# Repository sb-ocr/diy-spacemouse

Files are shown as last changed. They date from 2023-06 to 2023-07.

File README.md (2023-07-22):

# DIY Spacemouse for Fusion 360

Watch the build video ↓

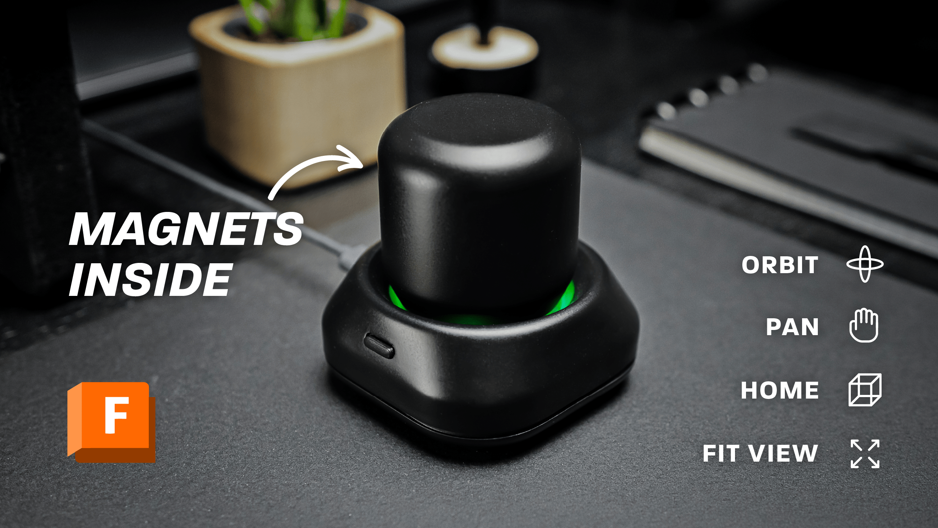
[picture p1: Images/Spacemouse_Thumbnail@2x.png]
[](https://youtu.be/iHBgNGnTiK4)

This device is made for Fusion360 but can be adapted to other CAD applications. Current features: Orbit, Pan, Home view and Fit to view.

Build instructions → [Instructables](https://www.instructables.com/DIY-Space-Mouse-for-Fusion-360-Using-Magnets)

[][cc-by-nc-sa]

[][cc-by-nc-sa]

[cc-by-nc-sa]: http://creativecommons.org/licenses/by-nc-sa/4.0/
[cc-by-nc-sa-image]: https://licensebuttons.net/l/by-nc-sa/4.0/88x31.png
[cc-by-nc-sa-shield]: https://img.shields.io/badge/License-CC%20BY--NC--SA%204.0-lightgrey.svg

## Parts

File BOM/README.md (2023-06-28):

Affiliate links may be included in the BOM. I may receive a small commission at no additional cost to you.

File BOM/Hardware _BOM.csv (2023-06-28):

Qty | Item | Link
6 | Round Magnets (6 × 2mm) | https://geni.us/0oCmMH
3 | Compression Spring 23/64" × 1-3/8" | https://geni.us/mm5tB
3 | Extension Spring 13/64" × 13/16" | https://geni.us/mm5tB
24 | M2.5 × 3.4 mm Heat-Set Inserts | https://geni.us/BMZYH
10 | M2.5 × 3mm Socket Head Screws | https://geni.us/S0KvnqZ
3 | M2.5 × 5mm Socket Head Screws | https://geni.us/S0KvnqZ
7 | M2.5 × 8mm Socket Head Screws | https://geni.us/S0KvnqZ
4 | M2.5 × 12mm Socket Head Screws | https://geni.us/S0KvnqZ

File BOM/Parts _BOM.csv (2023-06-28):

Qty | Item | Link
1 | QT Py RP2040 | https://www.adafruit.com/product/4900
1 | TLV493D Triple-Axis Magnetometer | https://www.adafruit.com/product/4366
1 | STEMMA QT / Qwiic JST SH 4-pin Cable - 100mm Long | https://www.adafruit.com/product/4210
2 | Tactile Button switch (6mm) | https://www.adafruit.com/product/367
3 | Adafruit LED Sequins - Emerald Green (optional) | https://www.adafruit.com/product/1756
4 | Rubber Bumper Feet | https://www.adafruit.com/product/550

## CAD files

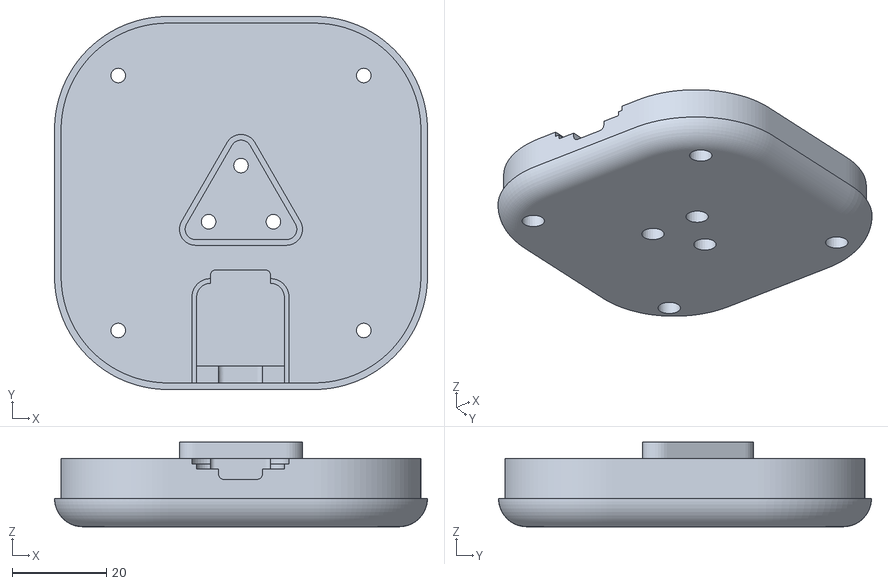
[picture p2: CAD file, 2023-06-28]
CAD/STLs/Base_bottom.stl
79.0 x 79.0 x 17.9

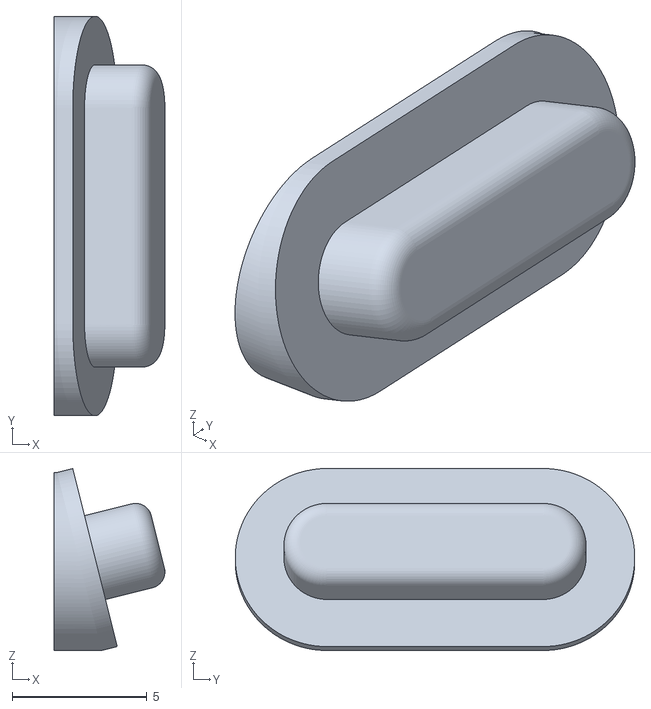
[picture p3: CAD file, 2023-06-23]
CAD/STLs/Buttons.stl
4.10 x 14.8 x 6.74

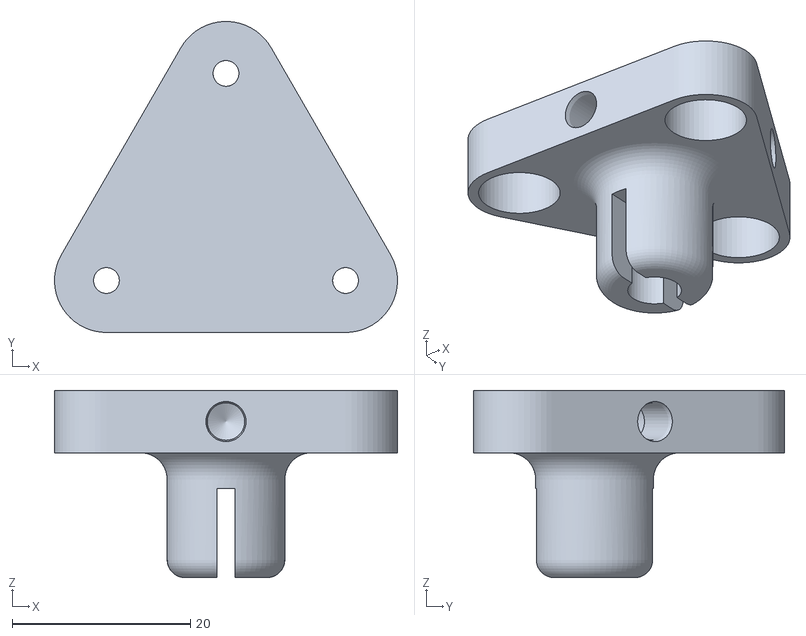
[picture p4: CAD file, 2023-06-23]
CAD/STLs/Stem_top.stl
38.4 x 34.9 x 21.0

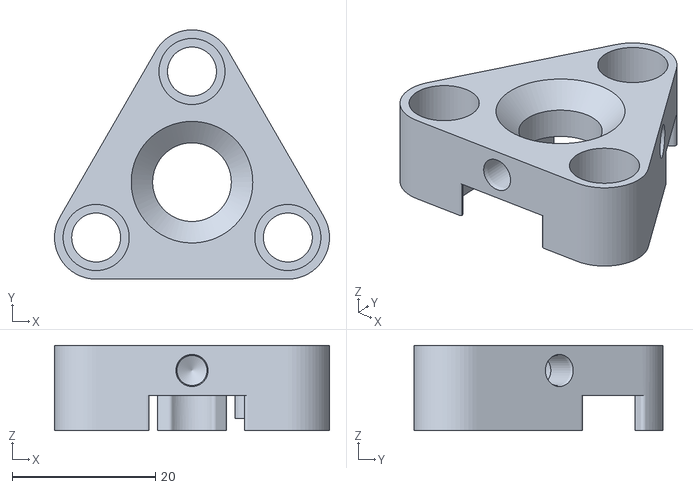
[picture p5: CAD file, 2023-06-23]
CAD/STLs/Stem_middle.stl
38.5 x 34.9 x 11.9

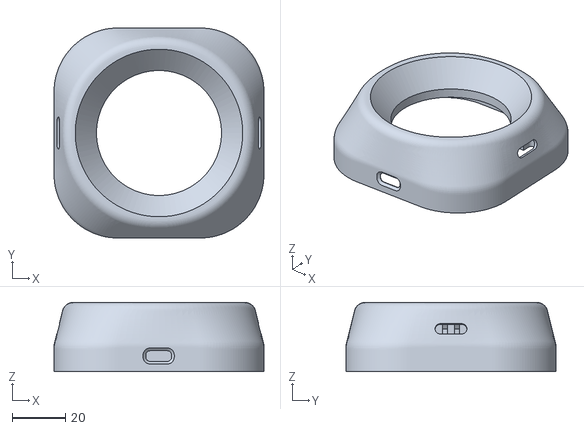
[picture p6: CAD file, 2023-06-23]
CAD/STLs/Base_top.stl
79.0 x 79.0 x 26.0

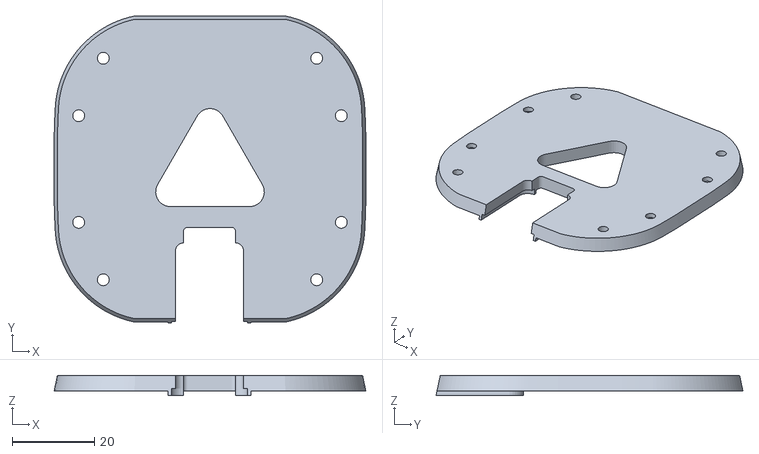
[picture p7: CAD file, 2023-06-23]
CAD/STLs/Base_middle_plate.stl
76.0 x 74.8 x 4.88

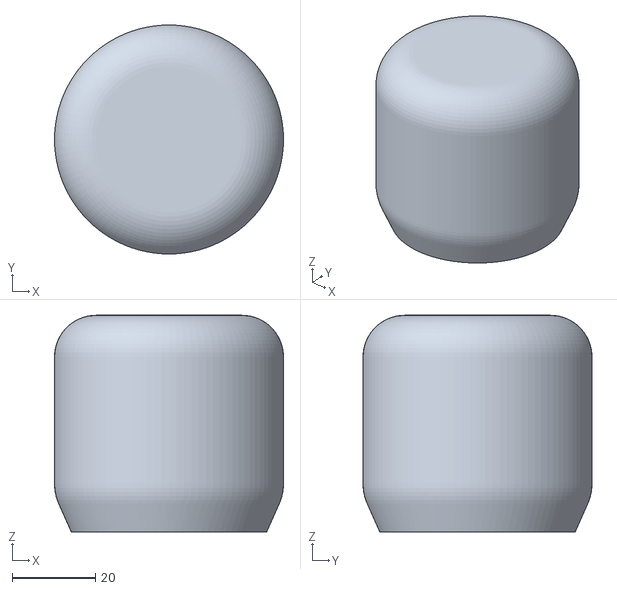
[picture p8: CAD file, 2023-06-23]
CAD/STLs/Knob.stl
55.0 x 55.0 x 52.0

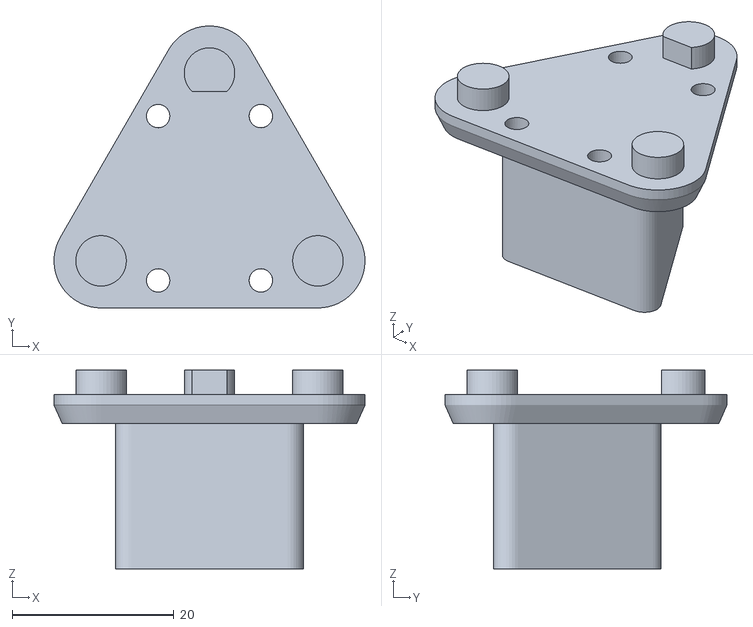
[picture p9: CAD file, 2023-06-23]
CAD/STLs/Stem_bottom.stl
38.4 x 34.9 x 24.6

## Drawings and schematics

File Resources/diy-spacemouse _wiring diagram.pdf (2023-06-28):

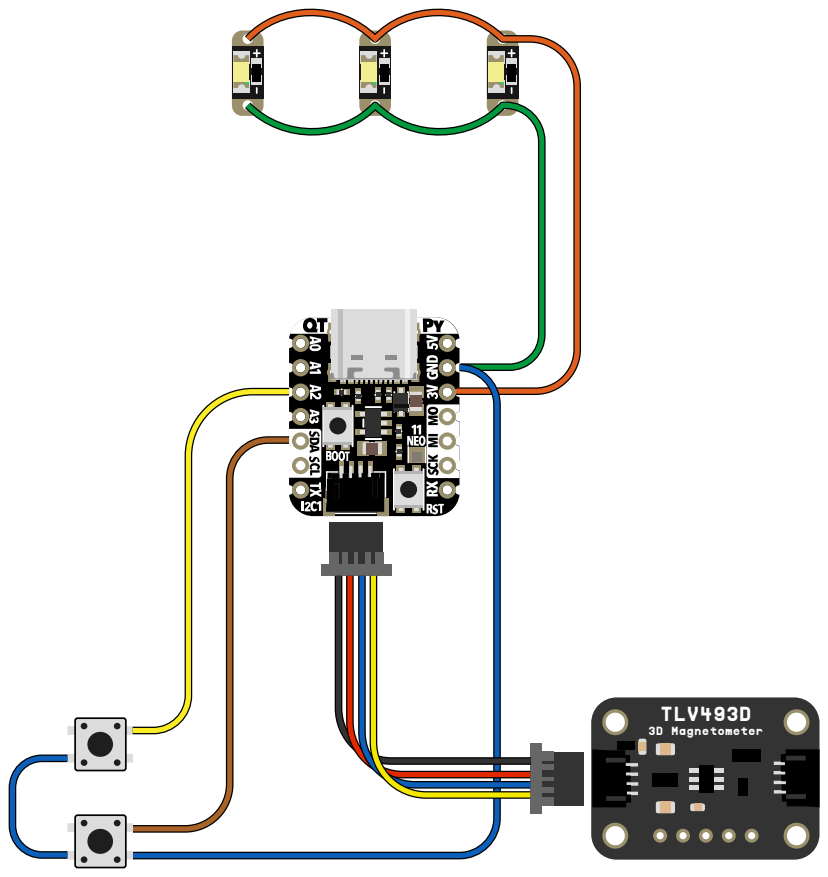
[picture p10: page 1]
TLV493D 3D Magnetometer

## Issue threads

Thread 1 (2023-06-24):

spacemouse pro emulation USB driver

Arbel-arad, 2023-06-24:
someone already made software for getting a pi pico to report and function as a full spacemouse (with software support)
this should be easy to convert for your hardware and function without locking out the mouse.
[https://github.com/jfedor2/magellan-spacemouse](https://github.com/jfedor2/magellan-spacemouse)

MohrJonas, 2023-06-24:
Great idea on your part 😀!
Most of the firmware seems relatively simple, but I've opened an issue in the repo you linked, asking about some of the more delicate inner workings, which the creator gladly explained: https://github.com/jfedor2/magellan-spacemouse/issues/2

Arbel-arad, 2023-06-24:
i can do packet capture on my spacemouse (enterprise) if that will help.
last time i tried to make custom descriptors it didn't work out, but the original version of this seems to be written well.

MohrJonas, 2023-06-24:
Yeah my hope is that all that has to be done is to throw out the code responsible for reading from the magellan mouse via UART and replace it with code that reads from the magnetometer via I2C

Ryder17z, 2023-06-25:
There is also https://github.com/lukenuttall/SpaceNavigatorEmulator  which might be interesting as inspiration

Arbel-arad, 2023-06-25:
that does look interesting but it requires loading a custom DLL file.
that isn't great for security, and also won't work in my main CAD program (onshape) because it's web based.
they are also emulating an older version of the device that is no longer supported by new 3DXware driver versions.

Ryder17z, 2023-06-25:
Those area good points. But also begs the question of difficulty in getting this working with Solidworks

LoganFraser, 2023-07-07:
Any updates on this? I finally have the adjustments to the base design I wanted (2 buttons per side, easier 3d printing, qwiic wire routed though the center of the support post) so I will be assembling and testing this weekend.

Arbel-arad, 2023-07-07:
until i can get a pi pico there probably won't be much progress.
though i hear the raspberry pi availability is starting to recover now.

Ryder17z, 2023-07-07:
The pico is not as badly affected by the shortage though?

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

LoganFraser, 2023-07-07:
You don't need a pico, any rp2040 will work.  I'm using a Seeeduino Xiao RP2040 for mine, same footprint as the bom part just no qwiic socket.

MohrJonas, 2023-07-08:
I'm working on it occasionally. The USB parts seems to work alright, but I'm having trouble getting the pico to read the sensor

LoganFraser, 2023-08-19:
> I'm working on it occasionally. The USB parts seems to work alright, but I'm having trouble getting the pico to read the sensor

Did you make any progress on this?  This seems like a useful device somewhat hindered by mouse/keyboard emulation restrictions.

MohrJonas, 2023-08-19:
Unfortunately, no

Arbel-arad, 2023-08-20:
i received the rp2040 board, but i don't have the sensors to test with them.
i will check if the interface driver works anyway, but it won't be very useful.

BeardedCobra48, 2023-08-23:
Hei there :D

Im also bit interested! :D

I bought a old CadMan Space Mouse (I love the looks and feling of it! even more than the one of the new 3dconnexion i use at work!)
SHAME ON 3Dconnexion for killing old hardware just because they can! :(

I am wondering if I can get my CAD Man to work like a new 3d connexion with a emulator like this?

Also I would love this to get big and spread it all accross the internet!

there are a lot of old 3d space mouses around that are just not usable because 3d connexion decided to kill them!!

Lets tell everyone there is a solution and f*ck 3dconnexion in their a*ss !! damn they deserve it!!

Ryder17z, 2023-08-28:
@BeardedCobra48
If I may be blunt: they do not even support modern products properly - why else would people be asking for over a decade to add dead-zone control? ([See thread from 2008](https://forum.3dconnexion.com/viewtopic.php?t=2120))

The current solution is really janky and involves modifying the config files for the official driver: https://forum.3dconnexion.com/viewtopic.php?t=16821   (but this applies to EVERY axis input)

It was not resolved in 2021 and I highly doubt it will ever be fixed officially.

I do not know if this project supports dead-zone control, but it would be awesome if it could be added with each axis independently adjustable, as per my own testing using multiple "Space Mouse Mini" on multiple computers has revealed it really needs little/none for up/down/rotation and some for the other axis; otherwise as soon as I take my hand off the device, it is almost guaranteed to fling the view a mile away from the object I'm working on in Solidworks.

RivasMario, 2023-09-12:
There is a value you can change in the code for dead zone. There is no official calibration test or setting for the spacemouse yet.

@LoganFraser how did you connect the seeduino without the qwik connector?

apadua, 2024-02-12:
> someone already made software for getting a pi pico to report and function as a full spacemouse (with software support) this should be easy to convert for your hardware and function without locking out the mouse. https://github.com/jfedor2/magellan-spacemouse

Can you tell me more about locking out the mouse? Are you saying when i deploy this code the normal mouse will stop moving? Have you tried working with it like this - does it break design flow significanly ( I assume it would)

A.

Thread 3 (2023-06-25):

BOM

CyborgGearVR, 2023-06-25:
Please include a Bill of Materials when you add your Build Instructions.  That way we can purchase the same springs and boards you did,  Thanks.

jrsall92, 2023-06-26:
I made a BOM and a pull request, in the mean time until it's accepted, you can find it here https://github.com/sb-ocr/diy-spacemouse/pull/4

mpx1986, 2023-06-28:
Can you please add the size of the magnets

sb-ocr, 2023-06-28:
> I made a BOM and a pull request, in the mean time until it's accepted, you can find it here #4

Thanks! I was already working on this update. I uploaded the exact parts and hardware [BOM](https://github.com/sb-ocr/diy-spacemouse/tree/main/BOM)

CyborgGearVR, 2023-07-01:
Thank you for the quick action on this.  Starting to work on one now.

TheUltimateAbsol, 2023-07-01:
BOM not clear on the screws and heatsets, see https://github.com/sb-ocr/diy-spacemouse/issues/9

Closed 2023-06-28.

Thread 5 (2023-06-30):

GY-521 sensor

axp-dev, 2023-06-30:
Hi, thanks for the project. You have inspired me to work. As in my country it is difficult to get the TLV493D, I will rework the inner triangle for the GY-521 sensor (MPU-6050). It will allow better position tracking.

When I come back from vacation, I will try to implement my ideas. And be sure to come here and show you the result.

V1s1S, 2023-07-08:
Привет, не поделишься переделанным проектом??

axp-dev, 2023-07-08:
@V1s1S на данный момент из готового это внутренний треугольник. Это единственное, что успел сделать и уехал до середины августа. Когда приеду напишу код для датчика.

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

Stout001, 2023-08-05:
Any progress on this. I also have plans using a MPU-6050/GY-521 and struggle with the code as I am also using a RP2040-Zero

dannybend, 2023-09-23:
Any progress on this?

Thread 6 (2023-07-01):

Script python error

Emmanuele75, 2023-07-01:
Hi, great project but I get this error:

C:\Users\titan\Downloads\diy-spacemouse-main\diy-spacemouse-main\Code\Fusion360 Add-in\Send Home>SendHome.py
Traceback (most recent call last):
  File "C:\Users\titan\Downloads\diy-spacemouse-main\diy-spacemouse-main\Code\Fusion360 Add-in\Send Home\SendHome.py", line 1, in <module>
    import adsk.core, adsk.fusion, adsk.cam, traceback
ModuleNotFoundError: No module named 'adsk'

How can I solve this problem?
Thanks!

Kudzmat, 2023-07-01:
This error occurs when you're trying to access or use a module that cannot be found, which means it's probably not installed on your computer.

Try typing 'pip install adsk' in your terminal first. Also, make sure you don't misspell the name of the module when installing. I hope this helps.

Emmanuele75, 2023-07-02:
Thanks for the suggestion, this issue has been resolved.
Anyway I can't start the script, I get this error:

Failed:
Traceback (most recent call last):
  File "C:/Users/emman/AppData/Roaming/Autodesk/Autodesk Fusion 360/API/AddIns/SpaceMouse/SpaceMouse.py", line 18, in run
    buttonSample = cmdDefs.addButtonDefinition('HomeViewButton',
  File "C:\Users/emman/AppData/Local/Autodesk/webdeploy/production/dbacedcc6dabacdc41406088a765962c5f1923ad/Api/Python/packages\adsk\core.py", line 5939, in addButtonDefinition
    return _core.CommandDefinitions_addButtonDefinition(self, *args)
RuntimeError: 3 : the relative resourceFolder path not found

LoganFraser, 2023-07-08:
You have a C:\ then the rest are /, that's probably the issue.

blasterlabs, 2023-07-27:
>

Hi, have you solve it? I've the same problem

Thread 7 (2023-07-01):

KM emulation: no-go

Renohedron, 2023-07-01:
Hi Salim, some time ago I built [Orbion](https://github.com/FaqT0tum/Orbion_3D_Space_Mouse) for exactly the same reasons you mention, but I never use it and always stick to my real SpaceMouse. The reason, which you maybe already realized if you used your DIY spacemouse for a bit, is you can't use keyboard/mouse emulation for a real work because your cursor, focus and everything is constantly taken away. I immediately noticed that by the end of your video, seeing mouse cursor slowly sliding away when you were rotating view. My point is that these devices are not much of use unless someone really dive into API you mentioned and program a full driver which doesn't emulate keystrokes and mouse movements. Any chance you would be interested in that after all?

sb-ocr, 2023-07-03:
Hi @Renohedron, yes, you are right. It's indeed annoying when the cursor gets taken away. This project was more of an exploration, and it's evident that there is interest from many people in building something similar. For the next iteration, it will be crucial to have the full 6DOF sensing and a better integration.

Here's an idea I had: Instead of using KM, we could emulate a gamepad HID. In the report, we can include (x, y, z, Rx, Ry, Rz), and then work on an Add-in on Fusion's side that can read these coordinates and directly control the camera. This imo will be more practical for other users who want to make it compatible with different software or explore a different use case altogether.

Closed 2023-07-03.

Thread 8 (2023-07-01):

A few suggestions for wider compatibility

LoganFraser, 2023-07-01:
There are many versions of the pi tiny sized rp2040 board but most don't have the i2c socket on them.  For future revisions, could you keep the i2c pins clear (4 and 5) and put the buttons on different inputs?  That would make it easier to connect to more versions.  Of course, I can just edit the pin file, and I'll have to for my seeed xiao rp2040 anyway to move the i2c.

A 3rd button could also be easily added (and I did).  Let me know if you're interested in the file, though I'm sure you can just as easily copy the existing button setup and rotate it 90 degrees to drop in a 3rd button.
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

for printability, having the shaft of the knob tapered all the way to the mounting plate means no supports needed.
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

Same for the bottom of the case, a chamfer first and then fillet on the top half means no overhang over 45 degrees.

Looking forward to the next version!  Thanks for sharing.  :)

sb-ocr, 2023-07-03:
Absolutely, there are some improvements that can be made for better printability, as you pointed out. I will definitely keep that in mind for the next iteration.

Regarding the buttons, I was thinking maybe the next one could have mini clusters of 2 or 3 on each side, leaving the "palm" side where you currently placed the third button clear, just because you rest your hand on it.

Thank you for the suggestions!

LoganFraser, 2023-07-04:
Tried out the 2 buttons per side thing.  I don't think there's room for 3, it starts getting really difficult into the rounded corners.  I had to move the mounting screws for the button plate 90 degrees.
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

I also added a wire path for the sensor down through the middle of the shaft.
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
I should have the sensor board in a few days, it's the only piece I'm still missing.  Thanks again.

Closed 2023-07-03.

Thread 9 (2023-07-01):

Size of the Heatset Insert?

TheUltimateAbsol, 2023-07-01:
Instructables says that it's a M2.5x3.4 heatset insert. I'm going to assume that 3.4 refers to the insert's outer diameter and not length.

When trying to order the part, it doesn't appear that 3.4 mm is a standard size, I can only find listings for 3.5 mm. Also I have no idea what length to order (3mm? 3.6mm? 4.0mm? 4.5mm? 5mm?)

The linked Amazon product only comes with M2.5x5, which doesn't even match the Instructables page.

Can I get a little bit of guidance here?

TheUltimateAbsol, 2023-07-01:
Furthermore the "M2.5 Socket Head Screws" are a bit confusing. The linked amazon item is for M3 Socket Head Screws and M2.5 Button Head Screws.

It appears Socket Head Screws are used in the video. Can I assume this link is incorrect?

sb-ocr, 2023-07-03:
You are right! It's a bit confusing.

I use a localization service for the Amazon links, which is supposed to match exact products in different countries. When a product is out of stock or unavailable, it moves to the "equivalent." However, sometimes it completely misses the mark.

The inserts I used are indeed **M2.5 x 3.4mm** in length*. I had some left over from a previous build, and I got them from [McMaster Carr](https://www.mcmaster.com/94180A321/) I found the closest equivalent from amazon that I will update and fix the links manually. Lengthwise, you can also use 3mm or 3.5mm. Just make sure that the diameter is around 4.5mm, or modify the holes accordingly.

Same goes for the screws. The link for Amazon(US) was incorrect. I manually updated it to fix the issue. They are M2.5 Socket Head screws, as seen in the video.

Thanks for bringing this to my attention!

unlucio, 2025-08-31:
Here, I found what inserts to get, at a reasonable price:

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

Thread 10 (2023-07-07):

Button 2 sharing SDA line: is this ok?

piecol, 2023-07-07:
Hi,

thanks for sharing this cool design!
I did not test the product yet, still waiting for components to arrive.

This is more of a question.. while I was going through the document of the buttons' wiring I notices you assigned button2 to pin 24, which happens to be the SDA line. Isn't it going to conflict with the TLV493D operation?
 ```c
// Setup buttons
OneButton button1(27, true);
OneButton button2(24, true);
 ```

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

sb-ocr, 2023-07-07:
Hi,

There are 2 I2C buses on the RP2040. The one connected to the button is not used to communicate with the TLV493D. It just happened to be closer when I was soldering the wires; there is no particular reason for choosing that pin.
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

Closed 2023-07-07.

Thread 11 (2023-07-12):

Code difficult to adjust

Launcherspider, 2023-07-12:
Hi, the way the code is made it is difficult to adjust to other CAD software, since Fusion360 is unique for using a additional button to toggle between orbit and pan-mode. Other programs use e.g. rigth-button+mouse-movment for orbiting and middle-mouse-button+mouse-movment for paning.
I tried to implement it, but it's not elegant at all
[See my code here](https://github.com/Launcherspider/3D-Spacemouse/blob/d7e678b6f59a59d49bb225627c3adee82e32c9d3/Code/OnShape_etc.ino)

> I switched what is triggered by pressing the knob and added different sensitivities for every mode. Also turned everything bei 90° to have the cable in the back.

RivasMario, 2023-08-15:
Has anyone implemented a way to use it for any other software than fusion 360. My python skills are middling and I wanted to adapt this to Davinci Resolve video editing software.

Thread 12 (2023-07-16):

6 Axis Sugestion

david0green94, 2023-07-16:
Hi,
How hard do you think it would be to modify the design for 6 axis? In the spirit of using parts laying around I realised a drone flight controller which are somewhat cheap and very available have at least 5 axis gyro + altitude. Just trying to work out how to pull the data from betaflight now.

LoganFraser, 2023-07-20:
That depends how big the flight controller pcb is, I'd imagine. Do you have a link for it?

sb-ocr, 2023-07-20:
I was playing with a similar idea by pairing the magnetometer readings with a gyro + accelerometer and calculating the Euler angles that way. That's why, in the first prototype, the sensor is placed on top of the platform. However, I found it a bit sticky and unreliable in terms of resolution for the amount of motion the knob is supposed to detect. It could be due to my poor programming, I only did a few quick tests, so I can't say for sure if t's the right approach or not.

stuart-warren, 2025-01-16:
There are a bunch of similar looking boards, I cant tell if they are actually useful here or not

* https://www.adafruit.com/product/4554
* https://www.adafruit.com/product/4754
* https://www.adafruit.com/product/4646

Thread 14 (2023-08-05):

3D Models for SLA Printing

maranhaoBruno, 2023-08-05:
Salim,

This is awesome, and I'd love to make my own, however; I have a SLA resin printer, and thus I cannot heat sink the threaded inserts, but have to press fit them in place. I was wondering if you could release STL files with the threaded insert positions increased to 4.5 mm in diameter. I tried to press fit some of the threaded inserts in and the holes are two small and the part ends up breaking apart. I opened the STEP file in FreeCAD, but I can't navigate down to the individual subelements of the larger parts, i.e. I can only get as far as "Spring Mech Top," "Sprint Mech Bottom," "Stem," and "Knob Shell" from the "Knob" part.

Thanks,
Bruno

RivasMario, 2023-08-15:
I believe he added the stl files.

https://github.com/sb-ocr/diy-spacemouse/tree/main/CAD/STLs

sb-ocr, 2023-08-18:
You can download the model in a few different formats from this [link](https://a360.co/3CR37TL)

Closed 2023-08-18.

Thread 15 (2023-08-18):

TinyUSB_Mouse_and_Keyboard.h

maranhaoBruno, 2023-08-18:
Where did you find TinyUSB_Mouse_and_Keyboard.h? I was able to install all the other libraries directly from the Arduino IDE except for this one. I found and installed this (https://github.com/cyborg5/TinyUSB_Mouse_and_Keyboard), but now I'm getting a fatal error that there is no HID.h. I thought I'd ask for help before going down a Depp deep rabbit hole.

Thanks,
B

sb-ocr, 2023-08-18:
That seem to be the correct one, you also have to change the USB stack to TinyUSB.
Check the usage section in this guide:
https://learn.adafruit.com/mouse-and-keyboard-control-using-tinyusb-and-ble/installing-the-libraries

Closed 2023-08-18.

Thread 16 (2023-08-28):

Alternatives!

amarkrish108, 2023-08-28:
Hi Salim,

Thanks for the Video, it's helpful.

I have a few questions related to it.

- How is it different from the Orbion?
- Is it usable in all 6 directions?
- Very Important "What are the Alternatives I can use"
- Especially the TLV493D Triple-Axis Magnetometer as it isn't available in my location.

If possible please suggest the Alternatives for all.

LoganFraser, 2023-08-28:
There's someone working on a GY-521 option here: https://github.com/sb-ocr/diy-spacemouse/issues/5

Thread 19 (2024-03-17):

Fusion file?

jdugan1024, 2024-03-17:
Hello,

Thank you for making this and sharing it. I've started assembling one and am looking forward to giving it a try.

I've run into a small snag. The threaded inserts I have are a little smaller in diameter than the ones you used. I thought hey, no problem there's a step file I can just tweak it. And that's true to an extent but editing a step file is not nearly as straightforward as editing the equivalent Fusion 360 file.

Would you be willing to include the Fusion file to the GitHub repository?

Thanks again for all your work in documenting and sharing this.

sb-ocr, 2024-03-19:
Hi, Checkout the Fusion embeds in the Instructables. It allows you to download in several formats Fusion Archive included.

Closed 2024-03-19.

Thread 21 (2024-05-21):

TLV493d - ADC hang up in Master Controlled or Fast Mode

Burke111-DEV, 2024-05-21:
How are you guys getting around the ADC hangup issue for the magnetometer?

I'm constantly getting lockups making it unusable.

geroulas, 2024-05-21:
Same here.. works for a few minutes, then stops. Any suggestions?

geroulas, 2024-05-22:
@Burke111-DEV  This code worked for me on Windows.. No hangups.
Still this projects feels a bit unusable, there is no smooth motion, no zoom..
It's a cool project but that's all, you cant work with this spacemouse.

Burke111-DEV, 2024-05-22:
@geroulas Thanks for sharing that project.
Unfortunately, that project just reposted precisely the same arduino sketch file that Salim created.
Any performance improvements are likely purely coincidental.
The hangup issue is unpredictably intermittent, so it may just be that you haven't experienced it _yet..._
My device sometimes lasts over an hour without issue, sometimes not even 10s. It's completely random.

I've made a lot of changes to Salim's original `diy-spacemouse.ino` file.
Key features I've added are
* Switchable 3D/2D mouse modes
* Unique sensitivities depending on the mode.
* **Dynamic speed based on how far you push the knob.**
  * Uses logarithmic function which you can adjust the curve using two variables. (One for max, other for sensitivity)
* **A scroll wheel for scrolling (zoom in Fusion)**

I'm quite happy with how it has turned out, and sounds like you might be interested in these features.

But I don't want to release my project details and files until I've got a solution to the intermittent hangup issue,,

---

For awareness, this is definitely a bug in the magnetometer, and not a quirk in the code.
See:
* https://community.infineon.com/t5/3D-Hall-Magnetic-sensor/TLV493-A1B6-lockup-crash-bug/td-p/344863
* https://community.infineon.com/t5/3D-Hall-Magnetic-sensor/TLV493D-3D-mag-sensor-not-robustly-reliable/td-p/296045

Additionally, the datasheet even mentions that it is a known issue, and comments in the official Infineon library for this sensor make reference to it.

Supposedly, the fix is to try to "reset" the device. But none of my attempts to do so have been successful. Was hoping someone might know something.

geroulas, 2024-05-22:
@Burke111-DEV woww man.. I was sure that was a different code.. but you are right! I was comparing it to the code I was running and I have altered some things compared to the original. I've been running it all moring without issues. Now that i got back from work, it hangs if I leave it alone for some minutes.. I also noticed that it **wont work If Serial Monitor is not open**. Íf I plug in the device, it will run for a few seconds then stops, if I open Arduino and Serial Monitor it stars working again. I close serial monitor and stops working. Maybe I've done something wrong, or maybe that helps you in some way...

In my case, I use the Waveshare RP2040-Zero, and in order to make it work I changes this
`Wire.begin();
mag.begin(Wire);`
Wire1 didn't work for me.

I will follow your links and try the reset method, see if I come up with something. I'm not really familiar with Arduino projects, but I will experiment.

I would love to see your project when you decide to release it! It will give life to this device for sure!

Burke111-DEV, 2024-05-23:
@geroulas
Regarding your issues with Wire vs Wire1:

Salim uses the Adafruit QT PY RP2040 in the original design. In particular, it is good for this project because it has the STEMMA connector which makes connecting up to the Adafruit TLV493d magnetometer module much simpler.
It's not that either of those two are required, just that they're a good match for ease of use (i.e., no need to solder the I2C pins).
So you're free to use any board, just you may need to do some more soldering.

TheAdafruit QT PY RP2040 has two I2C interfaces - i2c0 and i2c1. Both are usable, just two separate busses.
To communicate on i2c0 your code should use `Wire`. To communicate on i2c1 your code should use `Wire1`.

So presumably, the I2C bus you wired your magnetometer to on your RP2040uC board is the i2c0 one, so you need `Wire` instead of `Wire1` :)
---
If I can't find a solution to the intermittent issue soon, I'll likely just publish the details of my project anyway and hope someone sees it and can help solve the I2C lockup on there.

geroulas, 2024-05-23:
@Burke111-DEV Thanks for the input, I did read about all these, and now i'm in a good place now.

I think I have a something that might be working. I'm trying to re-initialize the sensor when it hangs.

I've added a code that compares the last values of the sensor with the previous ones. If xCurrent, yCurrent & zCurrent are exactly the same with xLast, yLast, zLast that must mean the sensor hang and reports the same values again and again.
It did work some times, I saw the code reporting back.

I've also remapped the two buttons. One button is jsut running the code to initialise the sensor. So when I see the knob not responding, I press the button and it's live again.

I read somewhere that by sending a 0x00 singal to the I2C it resets the sensor, so that's what i did here. I think it might be working even wihtout this and you just have initialize....

Also the entire code is doing Keyboard.press() and Keyboard.release all the time, I thinks that's bad for the controller. So I changed that part as well and I think it helps. Especially the shift key was not behaving well. The program was freezing and the Shift button was still pressed. For now I have it running only in Orbit mode (Fusion360).. just to see how it behaves.

Check the code, see if you can replicate this.

`#include <TinyUSB_Mouse_and_Keyboard.h>
#include <OneButton.h>
#include <Tlv493d.h>
#include <SimpleKalmanFilter.h>
#include <Wire.h>

Tlv493d mag = Tlv493d();
SimpleKalmanFilter xFilter(1, 1, 0.2), yFilter(1, 1, 0.2), zFilter(1, 1, 0.2);

// Setup buttons
OneButton button1(26, true);
OneButton button2(27, true);

float xOffset = 0, yOffset = 0, zOffset = 0;
float xCurrent = 0, yCurrent = 0, zCurrent = 0;
float xLast = 0, yLast = 0, zLast = 0;

int calSamples = 500;
int sensivity = 30;
int magRange = 3;
int outRange = 127;      // 127 Max allowed in HID report
float xyThreshold = 0.4; // Center threshold

int inRange = magRange * sensivity;
float zThreshold = 3;

bool isOrbit = false;

void setup()
{

  button1.attachClick(leftButton);
  button1.attachLongPressStop(leftButton);

  button2.attachClick(rightButton);
  button2.attachLongPressStop(rightButton);

  // mouse and keyboard init
  Mouse.begin();
  Keyboard.begin();

  Serial.begin(9600);
  Wire.begin();

  // mag sensor init
  mag.begin(Wire);
  mag.setAccessMode(mag.MASTERCONTROLLEDMODE);
  mag.disableTemp();

  // crude offset calibration on first boot
  for (int i = 1; i <= calSamples; i++)
  {

    delay(mag.getMeasurementDelay());
    mag.updateData();

    xOffset += mag.getX();
    yOffset += mag.getY();
    zOffset += mag.getZ();

    //Serial.print(".");
  }

  xOffset = xOffset / calSamples;
  yOffset = yOffset / calSamples;
  zOffset = zOffset / calSamples;

  xCurrent = xFilter.updateEstimate(mag.getX() - xOffset);
  yCurrent = yFilter.updateEstimate(mag.getY() - yOffset);
  zCurrent = zFilter.updateEstimate(mag.getZ() - zOffset);

  //Serial.println();
  Serial.println(xOffset);
  Serial.println(yOffset);
  Serial.println(zOffset);
}

void loop()
{

  // keep watching the push buttons
  button1.tick();
  button2.tick();

  // get the mag data
  delay(mag.getMeasurementDelay());
  mag.updateData();

  xLast = xCurrent;
  yLast = yCurrent;
  zLast = zCurrent;

  // update the filters
  xCurrent = xFilter.updateEstimate(mag.getX() - xOffset);
  yCurrent = yFilter.updateEstimate(mag.getY() - yOffset);
  zCurrent = zFilter.updateEstimate(mag.getZ() - zOffset);

  //Reset I2C if Sensor Hangs
  if(xLast == xCurrent && yLast == yCurrent && zLast == zCurrent)
  {
    Serial.println();
    Serial.print("RESETING");

    Mouse.begin();
    Keyboard.begin();
    Wire.beginTransmission(0x00);
    Wire.write(0x00);
    Wire.endTransmission();
    delay(1000);
    Wire.begin();
    mag.begin(Wire);
    mag.setAccessMode(mag.MASTERCONTROLLEDMODE);
    mag.disableTemp();

    Serial.println();
    Serial.print("RESET DONE");
  }

  // check the center threshold
  if (abs(xCurrent) > xyThreshold || abs(yCurrent) > xyThreshold)
  {
    int xMove = 0;
    int yMove = 0;

    // map the magnetometer xy to the allowed 127 range in HID repports
    xMove = map(xCurrent, -inRange, inRange, -outRange, outRange);
    yMove = map(yCurrent, -inRange, inRange, -outRange, outRange);

    // Orbit
    if (!Mouse.isPressed(MOUSE_MIDDLE))
    {
      Keyboard.press(KEY_LEFT_SHIFT);
      Mouse.press(MOUSE_MIDDLE);
      Serial.println();
      Serial.print("Mouse_Middle PRESSED");
    }

    Mouse.move(yMove, xMove, 0);
  }
  else
  {
    if (Mouse.isPressed(MOUSE_MIDDLE))
    {
      Mouse.release(MOUSE_MIDDLE);
      Keyboard.releaseAll();
      Serial.println();
      Serial.print("Mouse_Middle RELEASED");
    }
  }

  //Serial.print(xCurrent);
  //Serial.print(",");
  //Serial.print(yCurrent);
  //Serial.print(",");
  //Serial.print(zCurrent);
  //Serial.println();

}

// Fit to View (Fusion 360)
void leftButton()
{
  Mouse.press(MOUSE_MIDDLE);
  Mouse.release(MOUSE_MIDDLE);
  Mouse.press(MOUSE_MIDDLE);
  Mouse.release(MOUSE_MIDDLE);
}

// Initialize Mag Sensor
void rightButton()
{
  Serial.println();
  Serial.print("RESETING");

  Mouse.begin();
  Keyboard.begin();
  Wire.beginTransmission(0x00);
  Wire.write(0x00);
  Wire.endTransmission();
  delay(1000);
  Wire.begin();
  mag.begin(Wire);
  mag.setAccessMode(mag.MASTERCONTROLLEDMODE);
  mag.disableTemp();

  Serial.println();
  Serial.print("RESET DONE");
}

`

Burke111-DEV, 2024-06-04:
@geroulas
Not sure if that would work, but the general idea isn't wrong.
Interested to know if it worked for you.

On my end, I think I may have solved it.
It requires a change to the code inside the `Tlv493d` library files.
I just put up a comment explaining it under an issue I made on the Infineon project's repo:
https://github.com/Infineon/TLV493D-A1B6-3DMagnetic-Sensor/issues/25

Due to the completely random occurence of the bug, it's difficult to say with 100% certIainty that this is a definite fix.
But I have used my sensor for extended periods of time (4+ hrs) without issue for over a week now.

So I will post my code and 3D files when my free time permits :)

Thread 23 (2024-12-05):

RP2040-zero

lraton, 2024-12-05:
Is possible to use the rp2040-zero instead of the qt one? Obviously I can't use the Adafruit QT connectors and I'll have to solder them and change some pins, but otherwise can it work? It can fit on the prints?

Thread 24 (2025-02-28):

No Response from Mouse

McWitty, 2025-02-28:
Hello,

i'm a total noob in Arduino and programming it, but i would like to have this 3D Mouse for my CAD Projects. So i build this Mouse and got it working so far.
The LED's and the Buttons are working fine. But in the Arduino Monitor i get only an endless line running thru with this as response:

19:14:21.242 -> 0.00,0.00,0.00
19:14:21.242 -> 0.00,0.00,0.00
19:14:21.278 -> 0.00,0.00,0.00

What did i wrong?
I hope you can help me

lg
Tom

ThePsychedelicSeal, 2025-03-14:
I am having this same issue. Would really appreciate a solution if anyone could provide it.

bpivk, 2025-04-01:
Use this:
`#include <Adafruit_TinyUSB.h>
#include "TLx493D_inc.hpp"
#include <SimpleKalmanFilter.h>
#include <OneButton.h>

//--------------------------------------------------------------------+
// MSC RAM Disk Config
//--------------------------------------------------------------------+

Adafruit_USBD_MSC usb_msc;

enum {
  RID_KEYBOARD = 1,
  RID_MOUSE,
};

uint8_t const desc_hid_report[] = {
    TUD_HID_REPORT_DESC_KEYBOARD(HID_REPORT_ID(RID_KEYBOARD)),
    TUD_HID_REPORT_DESC_MOUSE   (HID_REPORT_ID(RID_MOUSE))
};

// USB HID object
Adafruit_USBD_HID usb_hid;

using namespace ifx::tlx493d;

/* Definition of the power pin and sensor objects for Kit2Go XMC1100 boards. */
const uint8_t POWER_PIN = 15; // XMC1100 : LED2

// some board swith multiple I2C need Wire --> Wire1
TLx493D_A1B6 mag(Wire1, TLx493D_IIC_ADDR_A0_e);

//Tlv493d mag = Tlv493d();
SimpleKalmanFilter xFilter(1, 1, 0.2), yFilter(1, 1, 0.2), zFilter(1, 1, 0.2);

// Setup buttons
OneButton button1(27, true);
OneButton button2(24, true);

float xOffset = 0, yOffset = 0, zOffset = 0;
float xCurrent = 0, yCurrent = 0, zCurrent = 0;

int calSamples = 50;
int sensivity = 8;
int magRange = 3;
int outRange = 127;      // Max allowed in HID report
float xyThreshold = 0.4; // Center threshold

int inRange = magRange * sensivity;
float zThreshold = xyThreshold * 2.5;

bool isOrbit = false;
bool middle = false;

uint8_t key_none[6] = {HID_KEY_NONE};
uint8_t key_h[6] = {HID_KEY_H};

/** Definition of a counter variable. */
uint8_t count = 0;

void calibrate() {
  double x, y, z;

  Wire1.begin();

  // mag sensor init
  mag.setPowerPin(POWER_PIN, OUTPUT, INPUT, HIGH, LOW, 0, 250000);
  mag.begin();

  for (int i = 1; i <= calSamples; i++)
  {
    mag.getMagneticField(&x, &y, &z);

    xOffset += x;
    yOffset += y;
    zOffset += z;
  }

  xOffset = xOffset / calSamples;
  yOffset = yOffset / calSamples;
  zOffset = zOffset / calSamples;

}

// the setup routine runs once when you press reset:
void setup() {
  // Manual begin() is required on core without built-in support e.g. mbed rp2040
  if (!TinyUSBDevice.isInitialized()) {
    TinyUSBDevice.begin(0);
  }

  usb_msc.begin();

  // Set up HID
  usb_hid.setReportDescriptor(desc_hid_report, sizeof(desc_hid_report));
  usb_hid.setBootProtocol(HID_ITF_PROTOCOL_NONE);
  usb_hid.setPollInterval(2);
  usb_hid.begin();

  if (TinyUSBDevice.mounted()) {
    TinyUSBDevice.detach();
    delay(10);
    TinyUSBDevice.attach();
  }

  Serial.begin(115200);
  calibrate();

  button1.attachClick(btn1);
  button2.attachClick(btn2);
}

void process_hid(int x, int y) {
  /*------------- Mouse -------------*/
  if (usb_hid.ready()) {
    usb_hid.mouseButtonPress(RID_MOUSE, MOUSE_BUTTON_MIDDLE);
    middle = true;
    delay(20);
    usb_hid.mouseReport(RID_MOUSE, MOUSE_BUTTON_MIDDLE, x, y, 0, 0 );
  }
}

void getMagnet() {
  double x, y, z;
  mag.getMagneticField(&x, &y, &z);

  xCurrent = xFilter.updateEstimate(x - xOffset);
  yCurrent = yFilter.updateEstimate(y - yOffset);
  zCurrent = zFilter.updateEstimate(z - zOffset);

  static uint32_t ms = 0;
  static uint32_t ms2 = 0;

  // check the center threshold
  if (abs(xCurrent) > xyThreshold || abs(yCurrent) > xyThreshold)
  {

    int xMove = 0;
    int yMove = 0;

    // map the magnetometer xy to the allowed 127 range in HID repports
    xMove = map(xCurrent, -inRange, inRange, -outRange, outRange);
    yMove = map(yCurrent, -inRange, inRange, -outRange, outRange);

    // press shift to orbit in Fusion 360 if the pan threshold is not corssed (zAxis)
    if (abs(zCurrent) > zThreshold)
    {
      usb_hid.keyboardReport(RID_KEYBOARD, KEYBOARD_MODIFIER_LEFTSHIFT, key_none);
      isOrbit = true;
      ms2 = millis();
    }

    // pan or orbit by holding the middle mouse button and moving propotionaly to the xy axis
    ms = millis();
    process_hid(xMove, -yMove);
  }
  else
  {
    // release the mouse and keyboard if within the center threshold
    if (millis() - ms > 200 && middle ) {
      usb_hid.mouseButtonRelease(RID_MOUSE);
      middle = false;
      delay(10);
    }
    if (millis() - ms2  > 200 && isOrbit) {
      usb_hid.keyboardRelease(RID_KEYBOARD);
      isOrbit = false;
      delay(10);
    }
  }

  Serial.print(xCurrent);
  Serial.print(",");
  Serial.print(yCurrent);
  Serial.print(",");
  Serial.print(zCurrent);
  Serial.println();
}

// the loop routine runs over and over again forever:
void loop() {
  // keep watching the push buttons
  button1.tick();
  button2.tick();

  #ifdef TINYUSB_NEED_POLLING_TASK
  // Manual call tud_task since it isn't called by Core's background
  TinyUSBDevice.task();
  #endif

  // not enumerated()/mounted() yet: nothing to do
  if (!TinyUSBDevice.mounted()) {
    return;
  }
  getMagnet();
}

void btn1()
{
  usb_hid.keyboardReport(RID_KEYBOARD, KEYBOARD_MODIFIER_LEFTSHIFT+KEYBOARD_MODIFIER_LEFTGUI, key_h);
  delay(10);
  usb_hid.keyboardRelease(RID_KEYBOARD);
}

void btn2()
{
  usb_hid.mouseButtonPress(RID_MOUSE, MOUSE_BUTTON_MIDDLE);
  delay(10);
  usb_hid.mouseButtonRelease(RID_MOUSE);
  delay(10);
  usb_hid.mouseButtonPress(RID_MOUSE, MOUSE_BUTTON_MIDDLE);
  delay(10);
  usb_hid.mouseButtonRelease(RID_MOUSE);
}`

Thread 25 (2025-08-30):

threads inserts issues

unlucio, 2025-08-30:
Hello everyone,

I've printed the parts, but I'm having an issue with the thread inserts:

1) Where can I find pictures or a diagram clearly pointing out all the 24 holes that need thread inserts?

2) I got 2.5M inserts, but all the holes are bigger than 3M 🥹

I printed it on an A1 mini.

unlucio, 2025-08-31:
I found the solutions to my problems, and I thought to share them for posterity.
Here are the inserts to buy, as well as pictures with all the holes that need them.

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

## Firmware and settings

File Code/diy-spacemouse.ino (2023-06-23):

#include <TinyUSB_Mouse_and_Keyboard.h>
#include <OneButton.h>
#include <Tlv493d.h>
#include <SimpleKalmanFilter.h>

Tlv493d mag = Tlv493d();
SimpleKalmanFilter xFilter(1, 1, 0.2), yFilter(1, 1, 0.2), zFilter(1, 1, 0.2);

// Setup buttons
OneButton button1(27, true);
OneButton button2(24, true);

float xOffset = 0, yOffset = 0, zOffset = 0;
float xCurrent = 0, yCurrent = 0, zCurrent = 0;

int calSamples = 300;
int sensivity = 8;
int magRange = 3;
int outRange = 127;      // Max allowed in HID report
float xyThreshold = 0.4; // Center threshold

int inRange = magRange * sensivity;
float zThreshold = xyThreshold * 1.5;

bool isOrbit = false;

void setup()
{

  button1.attachClick(goHome);
  button1.attachLongPressStop(goHome);

  button2.attachClick(fitToScreen);
  button2.attachLongPressStop(fitToScreen);

  // mouse and keyboard init
  Mouse.begin();
  Keyboard.begin();

  Serial.begin(9600);
  Wire1.begin();

  // mag sensor init
  mag.begin(Wire1);
  mag.setAccessMode(mag.MASTERCONTROLLEDMODE);
  mag.disableTemp();

  // crude offset calibration on first boot
  for (int i = 1; i <= calSamples; i++)
  {

    delay(mag.getMeasurementDelay());
    mag.updateData();

    xOffset += mag.getX();
    yOffset += mag.getY();
    zOffset += mag.getZ();

    Serial.print(".");
  }

  xOffset = xOffset / calSamples;
  yOffset = yOffset / calSamples;
  zOffset = zOffset / calSamples;

  Serial.println();
  Serial.println(xOffset);
  Serial.println(yOffset);
  Serial.println(zOffset);
}

void loop()
{

  // keep watching the push buttons
  button1.tick();
  button2.tick();

  // get the mag data
  delay(mag.getMeasurementDelay());
  mag.updateData();

  // update the filters
  xCurrent = xFilter.updateEstimate(mag.getX() - xOffset);
  yCurrent = yFilter.updateEstimate(mag.getY() - yOffset);
  zCurrent = zFilter.updateEstimate(mag.getZ() - zOffset);

  // check the center threshold
  if (abs(xCurrent) > xyThreshold || abs(yCurrent) > xyThreshold)
  {

    int xMove = 0;
    int yMove = 0;

    // map the magnetometer xy to the allowed 127 range in HID repports
    xMove = map(xCurrent, -inRange, inRange, -outRange, outRange);
    yMove = map(yCurrent, -inRange, inRange, -outRange, outRange);

    // press shift to orbit in Fusion 360 if the pan threshold is not corssed (zAxis)
    if (abs(zCurrent) < zThreshold && !isOrbit)
    {
      Keyboard.press(KEY_LEFT_SHIFT);
      isOrbit = true;
    }

    // pan or orbit by holding the middle mouse button and moving propotionaly to the xy axis
    Mouse.press(MOUSE_MIDDLE);
    Mouse.move(yMove, xMove, 0);
  }
  else
  {

    // release the mouse and keyboard if within the center threshold
    Mouse.release(MOUSE_MIDDLE);
    Keyboard.releaseAll();
    isOrbit = false;
  }

  Serial.print(xCurrent);
  Serial.print(",");
  Serial.print(yCurrent);
  Serial.print(",");
  Serial.print(zCurrent);
  Serial.println();
}

// go to home view in Fusion 360 by pressing  (CMD + SHIFT + H) shortcut assigned to the custom Add-in command
void goHome()
{
  Keyboard.press(KEY_LEFT_GUI);
  Keyboard.press(KEY_LEFT_SHIFT);
  Keyboard.write('h');

  delay(10);
  Keyboard.releaseAll();
  Serial.println("pressed home");
}

// fit to view by pressing the middle mouse button twice
void fitToScreen()
{
  Mouse.press(MOUSE_MIDDLE);
  Mouse.release(MOUSE_MIDDLE);
  Mouse.press(MOUSE_MIDDLE);
  Mouse.release(MOUSE_MIDDLE);

  Serial.println("pressed fit");
}

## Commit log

2023-06-23 YT video upload
    [Base_bottom.stl, Base_middle_plate.stl, Base_top.stl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]
2023-06-28 Build Instructions, wiring diagram, BOM and Base_bottom.stl fix
    [Base_bottom.stl, Base_middle_plate.stl, Base_top.stl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]

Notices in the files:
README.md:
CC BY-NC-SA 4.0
